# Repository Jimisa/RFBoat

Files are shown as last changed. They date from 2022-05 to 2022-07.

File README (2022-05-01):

This directory is intended for PlatformIO Unit Testing and project tests.

Unit Testing is a software testing method by which individual units of
source code, sets of one or more MCU program modules together with associated
control data, usage procedures, and operating procedures, are tested to
determine whether they are fit for use. Unit testing finds problems early
in the development cycle.

More information about PlatformIO Unit Testing:
- https://docs.platformio.org/page/plus/unit-testing.html

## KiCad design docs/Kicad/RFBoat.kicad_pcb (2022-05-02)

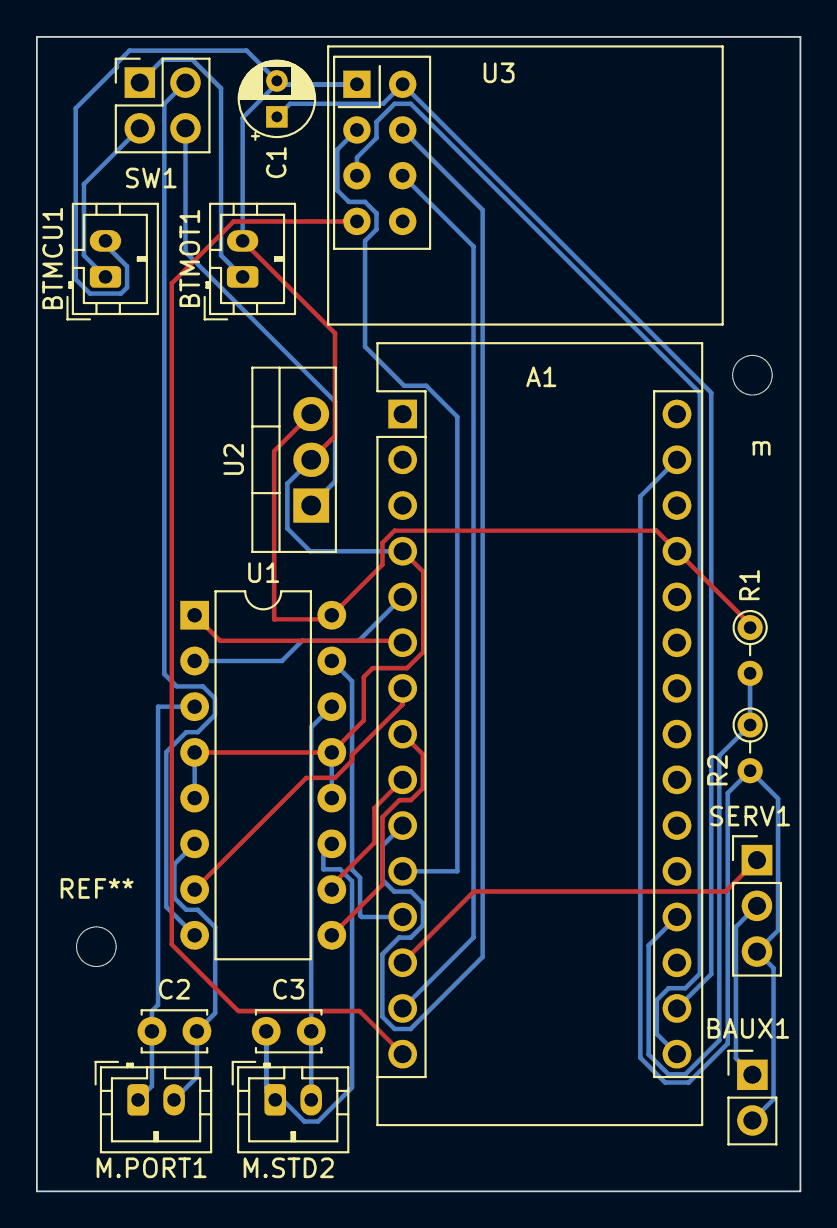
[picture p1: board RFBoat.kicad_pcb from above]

Board: 2 copper layers, 42.4 x 64.1 mm, 17 parts (0 on the bottom side), 26 nets.

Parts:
A1: Arduino_Nano_v3.x; Arduino_Nano
BAUX1: Battery; PinHeader_1x02_P2.54mm_Vertical
BTMCU1: 2*AAA; JST_PH_B2B-PH-K_1x02_P2.00mm_Vertical
BTMOT1: 9V; JST_PH_B2B-PH-K_1x02_P2.00mm_Vertical
C1: 10µF; CP_Radial_D4.0mm_P2.00mm
C2, C3: C; C_Disc_D3.4mm_W2.1mm_P2.50mm
M.PORT1: Port; JST_PH_B2B-PH-K_1x02_P2.00mm_Vertical
M.STD2: Starboard; JST_PH_B2B-PH-K_1x02_P2.00mm_Vertical
R1: R_Photo; R_Axial_DIN0204_L3.6mm_D1.6mm_P2.54mm_Vertical
R2: R; R_Axial_DIN0204_L3.6mm_D1.6mm_P2.54mm_Vertical
SERV1: Motor_Servo; PinHeader_1x03_P2.54mm_Vertical
SW1: SW_DPST; PinHeader_2x02_P2.54mm_Vertical
U1: L293D; DIP-16_W7.62mm
U2: 5V regulator; TO-220-3_Vertical
U3: NRF24L01_Breakout; nRF24L01_Breakout
m: MountingHole_2.2mm_M2

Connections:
GND: A1.4 (GND), BTMCU1.2 (-), BTMOT1.2 (-), C1.2, U1.4 (GND), U1.5 (GND), U1.12 (GND), U1.13 (GND), U2.2 (GND), U3.1 (GND)
unnamed: A1.5 (D2), U1.2 (1A)
unnamed: A1.6 (D3), U1.1 (EN1,2)
unnamed: A1.7 (D4), U1.7 (2A)
unnamed: A1.8 (D5), U1.9 (EN3,4)
unnamed: A1.9 (D6), U1.10 (3A)
unnamed: A1.12 (D9), U1.15 (4A)
unnamed: A1.13 (D10), SERV1.1 (PWM)
unnamed: A1.14 (D11), U3.6 (MOSI)
unnamed: A1.15 (D12), U3.7 (MISO)
unnamed: A1.16 (D13), U3.5 (SCK)
unnamed: A1.17 (3V3), C1.1, U3.2 (VCC)
unnamed: A1.19 (A0), R1.2, R2.1
unnamed: A1.27 (+5V), R1.1, U1.16 (VCC1), U2.3 (VO)
unnamed: A1.29 (GND), BAUX1.2 (-), R2.2, SERV1.3 (-)
unnamed: BAUX1.1 (+), SERV1.2 (+)
unnamed: BTMCU1.1 (+), SW1.3
unnamed: BTMOT1.1 (+), SW1.1
unnamed: C2.1, M.PORT1.1 (+), U1.3 (1Y)
unnamed: C2.2, M.PORT1.2 (-), U1.6 (2Y)
unnamed: C3.1, M.STD2.1 (+), U1.11 (3Y)
unnamed: C3.2, M.STD2.2 (-), U1.14 (4Y)
unnamed: SW1.2, U1.8 (VCC2)
unnamed: SW1.4, U2.1 (VI)
unnamed: A1.11 (D8), U3.3 (CE)
unnamed: A1.10 (D7), U3.4 (~CSN)

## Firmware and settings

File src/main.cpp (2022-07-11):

#include <Arduino.h>
#include <RF24.h>

/* channels configuration :
*  white  100
*  blue   102
*  green  104
*  red    106
*  yellow 108
*/
#define channel 108
#define motorPower 120

#define pinCE 8
#define pinCSN 7

// port motor
#define pinEN12 3
#define pinIN1 2
#define pinIN2 4

// starboard motor
#define pinEN34 5
#define pinIN3 6
#define pinIN4 9

RF24 radio(pinCE,pinCSN);

byte dataReceived;
int leftSignal, rightSignal;

String str ="";

void setup() {
  Serial.begin(9600);
  Serial.println("Hello Boat!");
  
  pinMode(pinEN12,OUTPUT);
  pinMode(pinIN1,OUTPUT);
  pinMode(pinIN2,OUTPUT);

  pinMode(pinEN34,OUTPUT);
  pinMode(pinIN3,OUTPUT);
  pinMode(pinIN4,OUTPUT);

  digitalWrite(pinIN1,LOW);
  digitalWrite(pinIN2,LOW);    
  
  radio.begin();

  radio.setChannel(channel);
  radio.setPALevel(RF24_PA_MIN);
  radio.setDataRate(RF24_1MBPS);

  radio.openReadingPipe(0,10101);

  radio.startListening();
}

void loop() {
  if (radio.available()) {
    radio.read(&dataReceived,sizeof(dataReceived));
    //Serial.print("Message reçu : ");
    Serial.println(dataReceived,BIN);
    leftSignal = dataReceived >> 4;
    rightSignal = dataReceived & byte(15);
    //Serial.println(str+"LeftSignal : "+leftSignal+", rightSignal : "+rightSignal);
    
    switch (leftSignal)
    {
    case 0:
      digitalWrite(pinIN1,HIGH);
      digitalWrite(pinIN2,LOW);
      analogWrite(pinEN12,motorPower);
      break;
    case 1:
      digitalWrite(pinIN1,LOW);
      digitalWrite(pinIN2,LOW);
      analogWrite(pinEN12,0);
      break;
    case 2:
      digitalWrite(pinIN1,LOW);
      digitalWrite(pinIN2,HIGH);
      analogWrite(pinEN12,motorPower);
      break;
    default:
      break;
    }
    switch (rightSignal)
    {
    case 0:
      digitalWrite(pinIN3,HIGH);
      digitalWrite(pinIN4,LOW);
      analogWrite(pinEN34,motorPower);
      break;
    case 1:
      digitalWrite(pinIN3,LOW);
      digitalWrite(pinIN4,LOW);
      analogWrite(pinEN34,0);
      break;
    case 2:
      digitalWrite(pinIN3,LOW);
      digitalWrite(pinIN4,HIGH);
      analogWrite(pinEN34,motorPower);
      default:
      break;
    }
  }
}

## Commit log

2022-05-01 init with CE pin 10 and CSN pin 9
2022-05-01 add kicad schematics and pcb according ti init pinout
    [RFBoat.kicad_pcb, RFBoat.kicad_sch]
2022-05-02 changed pin layout to free last PWM pin (10) CE & CSN
    [RFBoat.kicad_pcb, RFBoat.kicad_sch]
